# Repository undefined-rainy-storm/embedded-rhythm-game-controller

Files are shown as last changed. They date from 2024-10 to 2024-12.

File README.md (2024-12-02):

# Rhythm Game Controller

Rhythm Game Controller - Team Project for Embedded Software Lecture

## Getting Started

 - [`case_blueprint`](./case_blueprint) - Acrylic plate cutting drawing
 - [`circuit`](./circuit/) - Hardware circuit diagram
 - [`configurator`](./configurator/) - Controller key mapping program
 - [`controller`](./controller/) - Arduino controller
 - [`controller_test`](./controller_test/) - Unit test for `controller`
 - [`controller_verify`](./controller_verify/) - Verifying progress to check wire connection
 - [`presentation`](./presentation) - Presentation used in the assessment presentation

For more information see ["(KR) My team made a DJMAX arcade controller in the school lecture."](https://blog.jonghyeon.me/posts/2024-11-01-created-djmax-arcade-controller/).

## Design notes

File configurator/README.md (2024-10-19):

# configurator

A new Flutter project.

## Getting Started

This project is a starting point for a Flutter application.

A few resources to get you started if this is your first Flutter project:

- [Lab: Write your first Flutter app](https://docs.flutter.dev/get-started/codelab)
- [Cookbook: Useful Flutter samples](https://docs.flutter.dev/cookbook)

For help getting started with Flutter development, view the
[online documentation](https://docs.flutter.dev/), which offers tutorials,
samples, guidance on mobile development, and a full API reference.

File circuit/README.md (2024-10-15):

# Fritzing Resources

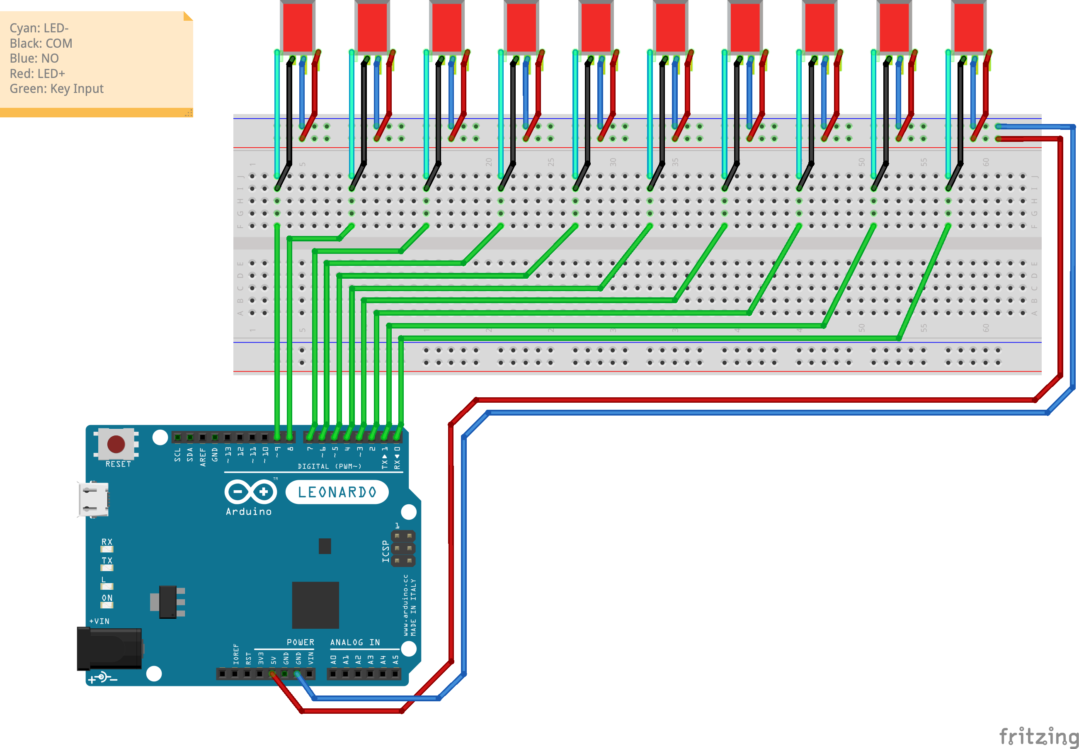
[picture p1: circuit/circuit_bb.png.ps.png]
  

Wire circuit diagram written with Fritzing 1.4.0

## If part resource is missed

Import part from [`./part`](./part/).

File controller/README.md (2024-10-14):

# Rhythm Game Controller: Arduino Sketch

## Requirements

### Hardware Compatibilities

This Sketch uses Keyboard and EEPROM. Because both API supports specific Arduino Model, one of below hardware required.

- Leonardo
- Micro
- Nano ESP32
- Uno R4 Minima
- Uno R4 WiFi

| Model | Keyboard API | EEPROM API |
| :-: | :-: | :-: |
| Leonardo | O | O |
| Micro | O | O |
| Due | O | |
| Zero | O | |
| UNO R4 Minima | O | O |
| UNO R4 WiFi | O | O |
| UNO R3 | | O |
| Giga R1 | O | |
| Nano | *1 | O |
| MKR Family | O | |

*1: Depends on model

For more information, visit [EEPROM](https://docs.arduino.cc/learn/programming/eeprom-guide/) and [Keyboard](https://docs.arduino.cc/libraries/keyboard/) documentation

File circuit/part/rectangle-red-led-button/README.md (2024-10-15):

# Arcade LED Button for Rhythm Game (CWB 405)

The CWB 405 button consists of a button, a switch, and an LED that can be separated.
The button part presses a switch, so only the switch and LED pins are supported.

It was written based on the 405 button set produced by IST (istmall.co.kr).
- LED: 5V DC, Unknown Manufacturer
- Switch: GSM-V0303A06, Gersung Engineering Micro Switch V Type

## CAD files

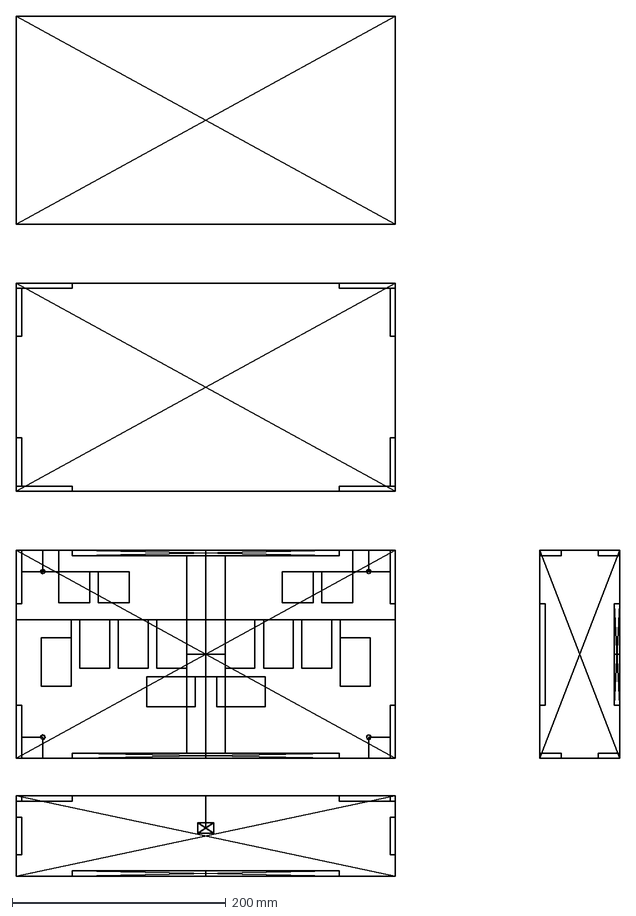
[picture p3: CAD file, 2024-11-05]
case_blueprint/entire.dxf
565.0 x 805.0 mm

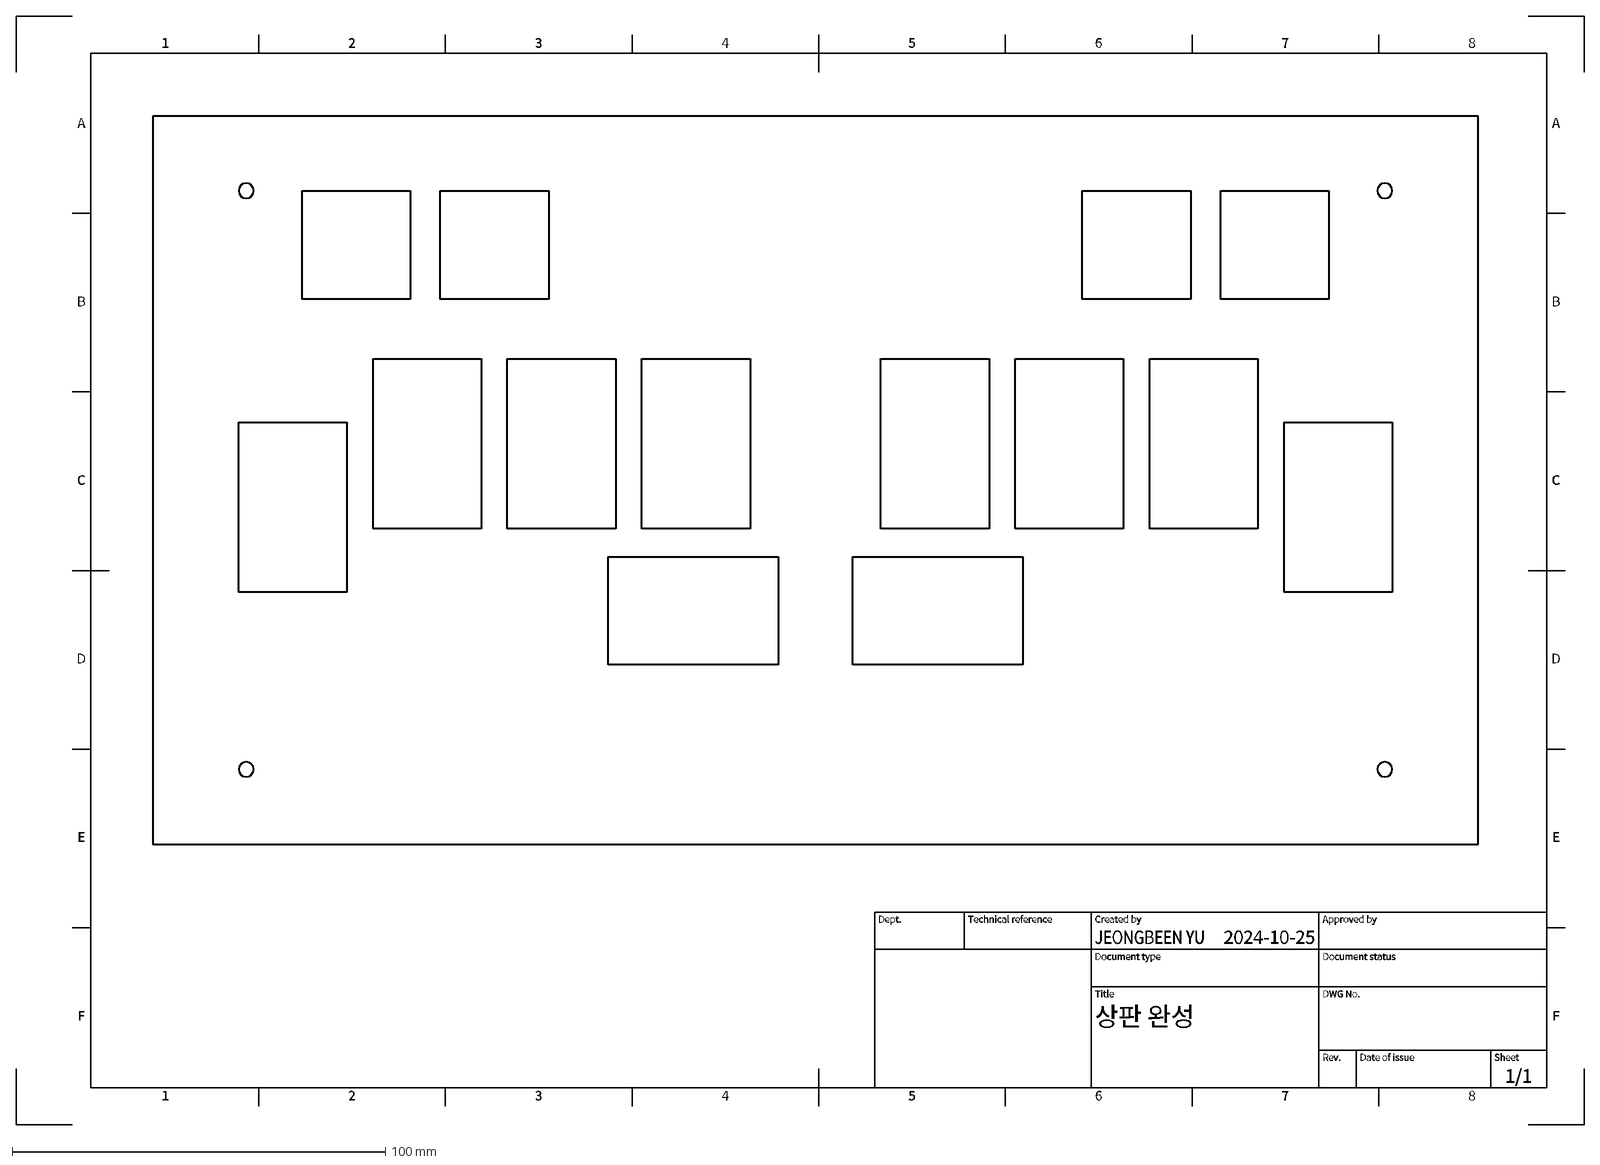
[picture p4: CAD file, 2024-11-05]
case_blueprint/top-revised.dxf
1
A
2
3
4
5
6
7
8
B
C
D
E
F
2024-10-25
1/1
상판 완성
JEONGBEEN YU
Dept.
Technical reference
Created by
Approved by
Document type
Document status
Title
DWG No.
Rev.
Date of issue
Sheet

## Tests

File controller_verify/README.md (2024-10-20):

# 하드웨어 조립 검증 코드

이 코드는 모든 기능이 정상 작동하는지, 제대로 조립되는지 검증합니다.
조립을 확정짓기 전에 보드에 업로드하여 사용하도록 의도되었습니다.

1. 하드웨어 요구사항을 만족하는 보드가 사용되었는가?
  평가 척도: 이 코드의 컴파일과 업로드가 이상 없이 완료되는가?
2. 모든 버튼의 입력이 문제 없이 인식되는가?
  평가 척도: 시리얼 출력으로 버튼 입력이 인식된다고 나타나는가?
3. 아두이노가 키보드 입력을 전송할 수 있는가?
  평가 척도: 문자 'k'를 시리얼 통신에 입력했을 때, 키보드 입력이 제대로 수행되는가?
4. 아두이노가 데이터를 저장할 수 있는가?
  평가 척도: 문자 'e'를 시리얼 통신에 입력했을 때, 데이터가 잘 저장되는가?

## 설정
만약 일부 기능만 확인하기 위해 하드웨어 요구사항을 부분적으로 충족하는 보드를 사용하는 경우, 컴파일이 제대로 수행되지 않을 수 있습니다.  

컴파일을 수행하기 전, 하드웨어가 지원하지 않는 기능은 비활성화해야합니다.  
```cpp
#define VERIFY_EEPROM   true  // EEPROM 검증 비활성화
#define VERIFY_KEYBOARD true  // 키보드 입력 검증 비활성화
```

그 외 몇 가지 설정을 수정할 수 있습니다.  
```cpp
#define SERIAL_SPEED    9600  // 시리얼 통신 속도

#define INPUT_CHAR_ON_VERIFY_KEYBOARD 'a'  // 키보드 입력 검증 시 누를 키
#define PRESSING_MILLISECONDS_ON_VERIFY_KEYBOARD 3000  // 키보드 입력 검증 시 키 누르는 시간
#define COMMAND_INVOKE_VERIFY_KEYBOARD 'k'  // 키보드 입력 검증 명령어
#define COMMAND_INVOKE_VERIFY_EEPROM 'e'  // 저장 검증 명령어
```

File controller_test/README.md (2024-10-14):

## Tests

```sh
cmake -S . -B build
cmake --build build
cd build && ctest
```

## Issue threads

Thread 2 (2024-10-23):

Revert button in `main_config_page` is not worked.

ShapeLayer, 2024-10-23:
It's seems to be because state not updated when `Global.instance.keyConfig` is changed.

For same cause, displaying saved configuration not worked too.

Closed 2024-10-25.

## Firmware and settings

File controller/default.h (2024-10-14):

#ifndef DEFAULT
#define DEFAULT

#define DEFAULT_KEY_ESC 177
#define DEFAULT_KEY_ENTER 176
#define DEFAULT_KEY_TAB 179
#define DEFAULT_KEY_SPACE -1
#define DEFAULT_KEY_SPEEDUP -1  // digit1
#define DEFAULT_KEY_SPEEDDOWN -1  // digit2
#define DEFAULT_KEY_REWINDKEY 178
#define DEFAULT_KEY_LEFTSHIFT 129
#define DEFAULT_KEY_RIGHTSHIFT 134
#define DEFAULT_KEY_ARROWUP 218
#define DEFAULT_KEY_ARROWDOWN 217
#define DEFAULT_KEY_ARROWLEFT 216
#define DEFAULT_KEY_ARROWRIGHT 215
#define DEFAULT_KEY_TUNELEFTSIDE 129
#define DEFAULT_KEY_TUNES 83
#define DEFAULT_KEY_TUNED 68
#define DEFAULT_KEY_TUNEF 70
#define DEFAULT_KEY_TUNEC 67
#define DEFAULT_KEY_TUNEM 77
#define DEFAULT_KEY_TUNEJ 74
#define DEFAULT_KEY_TUNEK 75
#define DEFAULT_KEY_TUNEL 76
#define DEFAULT_KEY_TUNERIGHTSIDE 134
#define DEFAULT_KEY_EMOTICON1 -1  // digit3
#define DEFAULT_KEY_EMOTICON2 -1  // digit4
#define DEFAULT_KEY_EMOTICON3 -1  // digit5
#define DEFAULT_KEY_EMOTICON4 -1  // digit6
#define DEFAULT_KEY_EMOTICON5 -1  // digit7

#endif

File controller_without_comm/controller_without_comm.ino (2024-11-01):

#include "config.h"
#include <Keyboard.h>

void setup() {
  pinMode(PIN_BUTTON_TUNE_LEFT_0, INPUT_PULLUP);
  pinMode(PIN_BUTTON_TUNE_LEFT_1, INPUT_PULLUP);
  pinMode(PIN_BUTTON_TUNE_LEFT_2, INPUT_PULLUP);
  pinMode(PIN_BUTTON_TUNE_LEFT_3, INPUT_PULLUP);
  pinMode(PIN_BUTTON_TUNE_LEFT_SIDE, INPUT_PULLUP);
  pinMode(PIN_BUTTON_TUNE_RIGHT_SIDE, INPUT_PULLUP);
  pinMode(PIN_BUTTON_TUNE_RIGHT_3, INPUT_PULLUP);
  pinMode(PIN_BUTTON_TUNE_RIGHT_2, INPUT_PULLUP);
  pinMode(PIN_BUTTON_TUNE_RIGHT_1, INPUT_PULLUP);
  pinMode(PIN_BUTTON_TUNE_RIGHT_0, INPUT_PULLUP);
  pinMode(PIN_BUTTON_SUB_LEFT_0, INPUT_PULLUP);
  pinMode(PIN_BUTTON_SUB_LEFT_1, INPUT_PULLUP);
  pinMode(PIN_BUTTON_SUB_RIGHT_0, INPUT_PULLUP);
  pinMode(PIN_BUTTON_SUB_RIGHT_1, INPUT_PULLUP);
}

void loop() {
  if (!digitalRead(PIN_BUTTON_TUNE_LEFT_0)) {
    Keyboard.press(KEYBOARD_BUTTON_TUNE_LEFT_0);
  } else {
    Keyboard.release(KEYBOARD_BUTTON_TUNE_LEFT_0);
  }
  if (!digitalRead(PIN_BUTTON_TUNE_LEFT_1)) {
    Keyboard.press(KEYBOARD_BUTTON_TUNE_LEFT_1);
  } else {
    Keyboard.release(KEYBOARD_BUTTON_TUNE_LEFT_1);
  }
  if (!digitalRead(PIN_BUTTON_TUNE_LEFT_2)) {
    Keyboard.press(KEYBOARD_BUTTON_TUNE_LEFT_2);
  } else {
    Keyboard.release(KEYBOARD_BUTTON_TUNE_LEFT_2);
  }
  if (!digitalRead(PIN_BUTTON_TUNE_LEFT_3)) {
    Keyboard.press(KEYBOARD_BUTTON_TUNE_LEFT_3);
  } else {
    Keyboard.release(KEYBOARD_BUTTON_TUNE_LEFT_3);
  }
  if (!digitalRead(PIN_BUTTON_TUNE_LEFT_SIDE)) {
    Keyboard.press(KEYBOARD_BUTTON_TUNE_LEFT_SIDE);
  } else {
    Keyboard.release(KEYBOARD_BUTTON_TUNE_LEFT_SIDE);
  }
  if (!digitalRead(PIN_BUTTON_TUNE_RIGHT_SIDE)) {
    Keyboard.press(KEYBOARD_BUTTON_TUNE_RIGHT_SIDE);
  } else {
    Keyboard.release(KEYBOARD_BUTTON_TUNE_RIGHT_SIDE);
  }
  if (!digitalRead(PIN_BUTTON_TUNE_RIGHT_3)) {
    Keyboard.press(KEYBOARD_BUTTON_TUNE_RIGHT_3);
  } else {
    Keyboard.release(KEYBOARD_BUTTON_TUNE_RIGHT_3);
  }
  if (!digitalRead(PIN_BUTTON_TUNE_RIGHT_2)) {
    Keyboard.press(KEYBOARD_BUTTON_TUNE_RIGHT_2);
  } else {
    Keyboard.release(KEYBOARD_BUTTON_TUNE_RIGHT_2);
  }
  if (!digitalRead(PIN_BUTTON_TUNE_RIGHT_1)) {
    Keyboard.press(KEYBOARD_BUTTON_TUNE_RIGHT_1);
  } else {
    Keyboard.release(KEYBOARD_BUTTON_TUNE_RIGHT_1);
  }
  if (!digitalRead(PIN_BUTTON_TUNE_RIGHT_0)) {
    Keyboard.press(KEYBOARD_BUTTON_TUNE_RIGHT_0);
  } else {
    Keyboard.release(KEYBOARD_BUTTON_TUNE_RIGHT_0);
  }
  if (!digitalRead(PIN_BUTTON_SUB_LEFT_0)) {
    Keyboard.press(KEYBOARD_BUTTON_SUB_LEFT_0);
  } else {
    Keyboard.release(KEYBOARD_BUTTON_SUB_LEFT_0);
  }
  if (!digitalRead(PIN_BUTTON_SUB_LEFT_1)) {
    Keyboard.press(KEYBOARD_BUTTON_SUB_LEFT_1);
  } else {
    Keyboard.release(KEYBOARD_BUTTON_SUB_LEFT_1);
  }
  if (!digitalRead(PIN_BUTTON_SUB_RIGHT_0)) {
    Keyboard.press(KEYBOARD_BUTTON_SUB_RIGHT_0);
  } else {
    Keyboard.release(KEYBOARD_BUTTON_SUB_RIGHT_0);
  }
  if (!digitalRead(PIN_BUTTON_SUB_RIGHT_1)) {
    Keyboard.press(KEYBOARD_BUTTON_SUB_RIGHT_1);
  } else {
    Keyboard.release(KEYBOARD_BUTTON_SUB_RIGHT_1);
  }
}

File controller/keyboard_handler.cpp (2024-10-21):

#include <Keyboard.h>
#include "pin.h"
#include "keyboard_handler.h"
#include "default.h"
#include "utils.h"
#include "global.h"

int _input_esc;
int _input_enter;
int _input_tab;
int _input_space;
int _input_speed_up;
int _input_speed_down;
int _input_rewind_key;
int _input_left_shift;
int _input_right_shift;
int _input_arrow_up;
int _input_arrow_down;
int _input_arrow_left;
int _input_arrow_right;
int _input_tune_left_side;
int _input_tune_s;
int _input_tune_d;
int _input_tune_f;
int _input_tune_c;
int _input_tune_m;
int _input_tune_j;
int _input_tune_k;
int _input_tune_l;
int _input_tune_right_side;
int _input_emoticon1;
int _input_emoticon2;
int _input_emoticon3;
int _input_emoticon4;
int _input_emoticon5;

bool _pressed_esc = false;
bool _pressed_enter = false;
bool _pressed_tab = false;
bool _pressed_space = false;
bool _pressed_speed_up = false;
bool _pressed_speed_down = false;
bool _pressed_rewind_key = false;
bool _pressed_left_shift = false;
bool _pressed_right_shift = false;
bool _pressed_arrow_up = false;
bool _pressed_arrow_down = false;
bool _pressed_arrow_left = false;
bool _pressed_arrow_right = false;
bool _pressed_tune_left_side = false;
bool _pressed_tune_s = false;
bool _pressed_tune_d = false;
bool _pressed_tune_f = false;
bool _pressed_tune_c = false;
bool _pressed_tune_m = false;
bool _pressed_tune_j = false;
bool _pressed_tune_k = false;
bool _pressed_tune_l = false;
bool _pressed_tune_right_side = false;
bool _pressed_emoticon1 = false;
bool _pressed_emoticon2 = false;
bool _pressed_emoticon3 = false;
bool _pressed_emoticon4 = false;
bool _pressed_emoticon5 = false;

Global *global = Global::getInstance();

void onSetup_beginPinModeAsInputPullup() {
  // Begin Button Pin Input
  if (PIN_BUTTON_ESC != undefined) { pinMode(PIN_BUTTON_ESC, INPUT_PULLUP); }
  if (PIN_BUTTON_ENTER != undefined) { pinMode(PIN_BUTTON_ENTER, INPUT_PULLUP); }
  if (PIN_BUTTON_TAB != undefined) { pinMode(PIN_BUTTON_TAB, INPUT_PULLUP); }
  if (PIN_BUTTON_SPACE != undefined) { pinMode(PIN_BUTTON_SPACE, INPUT_PULLUP); }
  if (PIN_BUTTON_SPEED_UP != undefined) { pinMode(PIN_BUTTON_SPEED_UP, INPUT_PULLUP); }
  if (PIN_BUTTON_SPEED_DOWN != undefined) { pinMode(PIN_BUTTON_SPEED_DOWN, INPUT_PULLUP); }
  if (PIN_BUTTON_REWIND_KEY != undefined) { pinMode(PIN_BUTTON_REWIND_KEY, INPUT_PULLUP); }
  if (PIN_BUTTON_LEFT_SHIFT != undefined) { pinMode(PIN_BUTTON_LEFT_SHIFT, INPUT_PULLUP); }
  if (PIN_BUTTON_RIGHT_SHIFT != undefined) { pinMode(PIN_BUTTON_RIGHT_SHIFT, INPUT_PULLUP); }
  if (PIN_BUTTON_ARROW_UP != undefined) { pinMode(PIN_BUTTON_ARROW_UP, INPUT_PULLUP); }
  if (PIN_BUTTON_ARROW_DOWN != undefined) { pinMode(PIN_BUTTON_ARROW_DOWN, INPUT_PULLUP); }
  if (PIN_BUTTON_ARROW_LEFT != undefined) { pinMode(PIN_BUTTON_ARROW_LEFT, INPUT_PULLUP); }
  if (PIN_BUTTON_ARROW_RIGHT != undefined) { pinMode(PIN_BUTTON_ARROW_RIGHT, INPUT_PULLUP); }
  if (PIN_BUTTON_TUNE_LEFT_SIDE != undefined) { pinMode(PIN_BUTTON_TUNE_LEFT_SIDE, INPUT_PULLUP); }
  if (PIN_BUTTON_TUNE_S != undefined) { pinMode(PIN_BUTTON_TUNE_S, INPUT_PULLUP); }
  if (PIN_BUTTON_TUNE_D != undefined) { pinMode(PIN_BUTTON_TUNE_D, INPUT_PULLUP); }
  if (PIN_BUTTON_TUNE_F != undefined) { pinMode(PIN_BUTTON_TUNE_F, INPUT_PULLUP); }
  if (PIN_BUTTON_TUNE_C != undefined) { pinMode(PIN_BUTTON_TUNE_C, INPUT_PULLUP); }
  if (PIN_BUTTON_TUNE_M != undefined) { pinMode(PIN_BUTTON_TUNE_M, INPUT_PULLUP); }
  if (PIN_BUTTON_TUNE_J != undefined) { pinMode(PIN_BUTTON_TUNE_J, INPUT_PULLUP); }
  if (PIN_BUTTON_TUNE_K != undefined) { pinMode(PIN_BUTTON_TUNE_K, INPUT_PULLUP); }
  if (PIN_BUTTON_TUNE_L != undefined) { pinMode(PIN_BUTTON_TUNE_L, INPUT_PULLUP); }
  if (PIN_BUTTON_TUNE_RIGHT_SIDE != undefined) { pinMode(PIN_BUTTON_TUNE_RIGHT_SIDE, INPUT_PULLUP); }
  if (PIN_BUTTON_EMOTICON1 != undefined) { pinMode(PIN_BUTTON_EMOTICON1, INPUT_PULLUP); }
  if (PIN_BUTTON_EMOTICON2 != undefined) { pinMode(PIN_BUTTON_EMOTICON2, INPUT_PULLUP); }
  if (PIN_BUTTON_EMOTICON3 != undefined) { pinMode(PIN_BUTTON_EMOTICON3, INPUT_PULLUP); }
  if (PIN_BUTTON_EMOTICON4 != undefined) { pinMode(PIN_BUTTON_EMOTICON4, INPUT_PULLUP); }
  if (PIN_BUTTON_EMOTICON5 != undefined) { pinMode(PIN_BUTTON_EMOTICON5, INPUT_PULLUP); }
}

inline void _changeKeyPressState(bool input, bool &pressed, int key) {
  if (input && !pressed) {
    Keyboard.press(key);
    pressed = true;
  } else if (!input && pressed) {
    Keyboard.release(key);
    pressed = false;
  }
}
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

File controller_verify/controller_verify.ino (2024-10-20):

/**
 * Controller Verify
 * 
 * This can be used to verify wire connection or well-assembled.
 * 
 * Checklist
 * 1. Is it well compiled and uploaded to the selected Arduino board?
 * 2. Are all buttons well recognized pressed or not?
 * 3. Can Arduino send keyboard input?
 *   Send 'k' character to Arduino through the serial monitor. (COMMAND_INVOKE_VERIFY_KEYBOARD)
 *   Then check the result through the serial monitor and keyboard output.
 * 4. Can Arduino save data?
 *   Send 'e' character to Arduino through the serial monitor. (COMMAND_INVOKE_VERIFY_EEPROM)
 *   Then check the result through the serial monitor.
 */

#define SERIAL_SPEED    9600
#define VERIFY_EEPROM   true
#define VERIFY_KEYBOARD true

#define INPUT_CHAR_ON_VERIFY_KEYBOARD 'a'
#define PRESSING_MILLISECONDS_ON_VERIFY_KEYBOARD 3000
#define COMMAND_INVOKE_VERIFY_KEYBOARD 'k'
#define COMMAND_INVOKE_VERIFY_EEPROM 'e'

#if VERIFY_EEPROM
#include <EEPROM.h>
#endif
#if VERIFY_KEYBOARD
#include <Keyboard.h>
#endif

bool pressingInvoked = false;
unsigned long pressingInvokedAt = -1;

void setup() {
  #if VERIFY_KEYBOARD
  Keyboard.begin();
  #endif

  Serial.begin(SERIAL_SPEED);
  pinMode(2, INPUT_PULLUP);
  pinMode(3, INPUT_PULLUP);
  pinMode(4, INPUT_PULLUP);
  pinMode(5, INPUT_PULLUP);
  pinMode(6, INPUT_PULLUP);
  pinMode(7, INPUT_PULLUP);
  pinMode(8, INPUT_PULLUP);
  pinMode(9, INPUT_PULLUP);
  pinMode(10, INPUT_PULLUP);
  while(!Serial);
  Serial.println("[Serial] Serial communication has been started.");
}

void loop() {
  #if VERIFY_KEYBOARD
  if (pressingInvoked) {
    unsigned long now = millis();
    if (millis() - pressingInvokedAt > PRESSING_MILLISECONDS_ON_VERIFY_KEYBOARD) {
      Keyboard.release(INPUT_CHAR_ON_VERIFY_KEYBOARD);
      Serial.print("[Keyboard] Pressing done. (Released at: ");
      Serial.print(now);
      Serial.println(")");
      pressingInvoked = false;
    } else {
    }
  }
  #endif
  
  char received = Serial.read();
  if (received == COMMAND_INVOKE_VERIFY_EEPROM) {
    verifyEEPROM();
  }
  if (received == COMMAND_INVOKE_VERIFY_KEYBOARD) {
    invokeVerifyKeyboard();
  }

  if (!digitalRead(2)) Serial.println("[Button] Button 2 has been pressed.");
  if (!digitalRead(3)) Serial.println("[Button] Button 3 has been pressed.");
  if (!digitalRead(4)) Serial.println("[Button] Button 4 has been pressed.");
  if (!digitalRead(5)) Serial.println("[Button] Button 5 has been pressed.");
  if (!digitalRead(6)) Serial.println("[Button] Button 6 has been pressed.");
  if (!digitalRead(7)) Serial.println("[Button] Button 7 has been pressed.");
  if (!digitalRead(8)) Serial.println("[Button] Button 8 has been pressed.");
  if (!digitalRead(9)) Serial.println("[Button] Button 9 has been pressed.");
}

void invokeVerifyKeyboard() {
  #if VERIFY_KEYBOARD
  pressingInvoked = true;
  Keyboard.write(INPUT_CHAR_ON_VERIFY_KEYBOARD);
  Serial.print("[Keyboard] `");
  Serial.print(INPUT_CHAR_ON_VERIFY_KEYBOARD);
  Serial.println("` has been wrote.");

  pressingInvokedAt = millis();
  Serial.print("[Keyboard] `");
  Serial.print(INPUT_CHAR_ON_VERIFY_KEYBOARD);
  Serial.print("` will be pressed for ");
  Serial.print(PRESSING_MILLISECONDS_ON_VERIFY_KEYBOARD);
  Serial.print(" milliseconds. (Started at: ");
  Serial.print(pressingInvokedAt);
  Serial.println(")");
  Keyboard.press(INPUT_CHAR_ON_VERIFY_KEYBOARD);
  #else
  Serial.println("[Keyboard] Keyboard verification has been disabled.");
  #endif
}

void verifyEEPROM() {
  const int origin = 1;
  const int address = 0;

  #if VERIFY_EEPROM
  int var = origin;
  Serial.print("[EEPROM] Variable is ");
  Serial.print(var);
  Serial.println(".");

  EEPROM.put(address, var);
  Serial.println("[EEPROM] Variable has been saved to EEPROM.");

  var = -1;
  Serial.print("[EEPROM] Variable has been changed to ");
  Serial.print(var);
  Serial.println(".");

  EEPROM.get(address, var);
  Serial.println("[EEPROM] Variable has been loaded from EEPROM.");
  
  Serial.print("[EEPROM] Verify ");
  Serial.print(var == origin ? "passed" : "failed");
  Serial.print(": `");
  Serial.print(origin);
  Serial.print("` Expected, ");
  Serial.print("`");
  Serial.print(var);
  Serial.println("` Found.");
  #else
  Serial.println("[EEPROM] EEPROM verification has been disabled.");
  #endif
}

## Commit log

2024-10-08 feat: add ConfigKeyField and DropdownList for Selecting Serial Device
    Issue to be resolved: libserialport cannot be loaded in macOS system
2024-10-11 feat: add serial devices support, magic number
2024-10-14 chore: Refactor implement, Remove `button_config`
2024-10-15 feat: Add Fritzing Resources
    [controller.fzz]
2024-10-15 fix: fix part pin mismatch
2024-10-15 fix: fix circuit error
    [circuit.fzz, controller.fzz]
2024-10-16 feat: Add hardware assembling verifier
2024-10-16 fix: Remove rx/tx from button verify from controller_verify
    [controller_verify.ino]
2024-10-17 feat: Add pin button on pressed handler
2024-10-17 chore: Seperate pin button input handler
2024-10-19 feat: Add serial device selector badge
2024-10-20 fix: Verifying keyboard input stops when write() before release()
    [controller_verify.ino]
2024-10-21 fix: keyboard key pressed on idle, swapping device selection is blocked
    [controller.ino, keyboard_handler.cpp, pin.h]
2024-10-21 feat: Add save and revert device KeyConfig (without serial communication)
2024-11-05 chore: add case blueprint
    [entire.dxf, top-revised.dxf]
